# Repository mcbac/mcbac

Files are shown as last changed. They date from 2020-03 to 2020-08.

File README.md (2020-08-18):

# MCBAC

**M**ulti **C**hemistry **B**attery **A**nalyzer and **C**harger - The Software
and Schematic.

MCBAC is a open source (schematic and software), Arduino controled (atmega238),
battery charger and analyzer designed for common battery types. Also can mimic
a power supply, and electronic load.

Comming by late 2020 to mid 2021.

## Purpose

The main purpose of the MCBAC is a affordable, all made in USA, battery
charger, discharger, and analyzer. Able to test batteries of all shapes and
sizes.

## Specification

Please see the [mcbac-v2/README.md](./mcbac-v2/README.md) for details.

## Roadmap

_The roadmap is subject to change without notice._

MCBAC V2.X will be available in low production quantities (maybe 25 units) in
late 2020 to mid 2021. If that is successful, V3 will include cell balancing,
PC/USB controll, and higher output capability, and will be avalibale in higher
quantities (50-100 units).

## License

All files owned by the MCBAC designer(s) and/or MCBAC Technology (the company)
are licensed under the terms of **The Clear BSD License**. See the
[LICENSE file](./LICENSE) for more details.

<br>

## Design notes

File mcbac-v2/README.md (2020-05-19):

# MCBAC Version 2

Comming by late fall 2020 to mid 2021.

These are the design files for mcbac-v2.

## Specification

_Since this is still in pre-production, the specification is subject to change
without notice._

### Input/output
 - Input volts: 7-24v (28v max) (maximum output volts will be 2 volts below the input)
 - Input current: 2.5A max
 - Output volts: 0-15v
 - Output source current: 0-2A
 - Output sink current: 0-2A
 - Output type: linear with buck pre-regulator
 - External temperature sensor (10K NTC)

### Interface
 - 20x4 backlit LCD
 - 2 push buttons
 - 24 step rotary encoder
 - Internal buzzer

### Physical
 - Case: na (dimension not yet available)
 - Internal fan
 - Input: DC power jack (type not yet available)
 - Output: 2X banana jacks
 - Temperature sensor conector: 2 pin JST

<br>

For other infomation about the MCBAC project, see [../README.md](../README.md).

<br>

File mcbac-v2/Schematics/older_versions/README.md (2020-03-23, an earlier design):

This folder contains the older or pre-releases versions of the MCBAC circuit.
See the schematic CHANGELOG for more detail.

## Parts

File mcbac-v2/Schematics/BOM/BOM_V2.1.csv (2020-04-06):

Manufacturer Part Number | Manufacturer | Digi-Key Part Number | Customer Reference | Reference Designator | Packaging | Part Status | Quantity | Unit Price | Extended Price | Description
C0805C104Z5VACTU | KEMET | 399-1177-1-ND |  |  | Cut Tape (CT) | Active | 20 | 0.05700 | $1.14 | CAP CER 0.1UF 50V Y5V 0805
C0805C103K1RAC7210 | KEMET | 399-17617-1-ND |  |  | Cut Tape (CT) | Active | 20 | 0.06800 | $1.36 | CAP CER SMD 0805 .01UF 100V X7R
C0805C220J5GACTU | KEMET | 399-1113-1-ND |  |  | Cut Tape (CT) | Active | 20 | 0.07000 | $1.40 | CAP CER 22PF 50V C0G/NP0 0805
C0805C102J5GACTU | KEMET | 399-1136-1-ND |  |  | Cut Tape (CT) | Active | 20 | 0.09500 | $1.90 | CAP CER 1000PF 50V C0G/NP0 0805
MMBT3906-7-F | Diodes Incorporated | MMBT3906-FDICT-ND |  |  | Cut Tape (CT) | Active | 2 | 0.12000 | $0.24 | TRANS PNP 40V 0.2A SOT23-3
MMBT2907A-7-F | Diodes Incorporated | MMBT2907A-FDICT-ND |  |  | Cut Tape (CT) | Active | 2 | 0.13000 | $0.26 | TRANS PNP 60V 0.6A SOT23-3
MCP6002T-I/SN | Microchip Technology | MCP6002T-I/SNCT-ND |  |  | Cut Tape (CT) | Active | 3 | 0.33000 | $0.99 | IC OPAMP GP 2 CIRCUIT 8SOIC
0751.0062 | Schurter Inc. | 486-1172-ND |  |  | Bulk | Active | 4 | 0.17000 | $0.68 | FUSE CLIP CARTRIDGE 10A PCB
S1M-13-F | Diodes Incorporated | S1M-FDICT-ND |  |  | Cut Tape (CT) | Active | 25 | 0.16360 | $4.09 | DIODE GEN PURP 1KV 1A SMA
ERJ-3GEYJ222V | Panasonic Electronic Components | P2.2KGCT-ND |  |  | Cut Tape (CT) | Active | 10 | 0.04500 | $0.45 | RES SMD 2.2K OHM 5% 1/10W 0603
ERJ-3GEYJ102V | Panasonic Electronic Components | P1.0KGCT-ND |  |  | Cut Tape (CT) | Active | 30 | 0.04400 | $1.32 | RES SMD 1K OHM 5% 1/10W 0603
ERJ-3GEYJ103V | Panasonic Electronic Components | P10KGCT-ND |  |  | Cut Tape (CT) | Active | 30 | 0.04200 | $1.26 | RES SMD 10K OHM 5% 1/10W 0603
ESR03EZPJ101 | Rohm Semiconductor | RHM100DCT-ND |  |  | Cut Tape (CT) | Active | 2 | 0.10000 | $0.20 | RES SMD 100 OHM 5% 1/4W 0603
CRGCQ0603J22K | TE Connectivity Passive Product | A130099CT-ND |  |  | Cut Tape (CT) | Active | 10 | 0.02100 | $0.21 | CRGCQ 0603 22K 5%
RMCF0603FT29K4 | Stackpole Electronics Inc | 738-RMCF0603FT29K4CT-ND |  |  | Cut Tape (CT) | Active | 2 | 0.10000 | $0.20 | RES 29.4K OHM 1% 1/10W 0603
TPS54331DDAR | Texas Instruments | 296-39419-1-ND |  |  | Cut Tape (CT) | Active | 2 | 1.50000 | $3.00 | IC REG BUCK ADJUSTABLE 3A 8SOPWR
LT3083EQ#TRPBF | Linear Technology/Analog Devices | LT3083EQ#TRPBFCT-ND |  |  | Cut Tape (CT) | Active | 1 | 10.44000 | $10.44 | IC REG LINEAR POS ADJ 3A 5DDPAK
B340A-13-F | Diodes Incorporated | B340A-FDICT-ND |  |  | Cut Tape (CT) | Active | 2 | 0.41000 | $0.82 | DIODE SCHOTTKY 40V 3A SMA
860020573008 | Würth Elektronik | 732-8942-1-ND |  |  | Cut Tape (CT) | Active | 2 | 0.14000 | $0.28 | CAP ALUM 100UF 20% 35V RADIAL
860020572001 | Würth Elektronik | 732-8935-1-ND |  |  | Cut Tape (CT) | Active | 2 | 0.10000 | $0.20 | CAP ALUM 4.7UF 20% 35V RADIAL
SDE0604A-5R6M | Bourns Inc. | SDE0604A-5R6MCT-ND |  |  | Cut Tape (CT) | Active | 1 | 0.64000 | $0.64 | FIXED IND 5.6UH 3.2A 75 MOHM SMD
TIP122 | STMicroelectronics | 497-2543-5-ND |  |  | Tube | Active | 2 | 0.64000 | $1.28 | TRANS NPN DARL 100V 5A TO-220
NCP1117DT50G | ON Semiconductor | NCP1117DT50GOS-ND |  |  | Tube | Active | 1 | 0.41000 | $0.41 | IC REG LINEAR 5V 1A DPAK
MCP4725A1T-E/CH | Microchip Technology | MCP4725A1T-E/CHCT-ND |  |  | Cut Tape (CT) | Active | 2 | 0.96000 | $1.92 | IC DAC 12BIT V-OUT SOT23-6
ADS1115IDGSR | Texas Instruments | 296-38849-1-ND |  |  | Cut Tape (CT) | Active | 1 | 5.36000 | $5.36 | IC ADC 16BIT SIGMA-DELTA 10VSSOP
61301011821 | Würth Elektronik | 732-2859-ND |  |  | Tray | Active | 1 | 0.65000 | $0.65 | CONN HDR 10POS 0.1 GOLD PCB
CMI-1295-0585T | CUI Devices | 102-CMI-1295-0585T-ND |  |  | Box | Active | 1 | 1.17000 | $1.17 | BUZZER, 12 MM X 9.5 MM DEEP, M,
MMBT3904-7-F | Diodes Incorporated | MMBT3904-FDICT-ND |  |  | Cut Tape (CT) | Active | 10 | 0.10600 | $1.06 | TRANS NPN 40V 0.2A SMD SOT23-3
LM358DT | STMicroelectronics | 497-1591-1-ND |  |  | Cut Tape (CT) | Active | 2 | 0.46000 | $0.92 | IC OPAMP GP 2 CIRCUIT 8SO
04JQ-BT | JST Sales America Inc. | 455-2967-ND |  |  | Bulk | Active | 1 | 0.43000 | $0.43 | CONN RCPT 4POS 0.098 TIN PCB
B4B-XH-A(LF)(SN) | JST Sales America Inc. | 455-2249-ND |  |  | Bulk | Active | 1 | 0.21000 | $0.21 | CONN HEADER VERT 4POS 2.5MM
08JQ-BT | JST Sales America Inc. | 455-2970-ND |  |  | Bulk | Active | 1 | 0.53000 | $0.53 | CONN RCPT 8POS 0.098 TIN PCB
B8B-XH-AM(LF)(SN) | JST Sales America Inc. | 455-2232-ND |  |  | Bulk | Active | 1 | 0.37000 | $0.37 | CONN HEADER VERT 8POS 2.5MM
3049 | Keystone Electronics | 36-3049-ND |  |  | Bulk | Active | 2 | 0.15000 | $0.30 | WASHER SHOULDER #4 NYLON
HF115AC-0.0055-AC-54 | Bergquist | BER167-ND |  |  | Bulk | Active | 2 | 0.10000 | $0.20 | THERM PAD 19.05MMX12.7MM W/ADH
MF52A2103J3470 | Cantherm | 317-1258-ND |  |  | Bulk | Active | 1 | 0.43000 | $0.43 | THERMISTOR NTC 10KOHM 3470K BEAD
LEDM-2-08 | Essentra Components | RPC4261-ND |  |  | Bulk | Active | 1 | 0.38000 | $0.38 | LED SPACER 3MM T-1 BLACK 8MM
PEC16-4220F-N0024 | Bourns Inc. | PEC16-4220F-N0024-ND |  |  | Tray | Active | 1 | 1.28000 | $1.28 | ROTARY ENCODER MECHANICAL 24PPR
5MF 5-R | Bel Fuse Inc. | 507-1269-ND |  |  | Box | Active | 2 | 0.24000 | $0.48 | FUSE GLASS 5A 125VAC 5X20MM
G5LE-14 DC5 | Omron Electronics Inc-EMC Div | Z1011-ND |  |  | Tray | Active | 2 | 1.44000 | $2.88 | RELAY GEN PURPOSE SPDT 10A 5V
V8818V | Assmann WSW Components | AE10831-ND |  |  | Tray | Active | 2 | 1.50000 | $3.00 | HEATSINK ALUM ANOD
ERT-J1VR103H | Panasonic Electronic Components | P13707CT-ND |  |  | Cut Tape (CT) | Active | 2 | 0.19000 | $0.38 | THERMISTOR NTC 10KOHM 4250K 0603
TFPT0603L1001FM | Vishay Dale | 541-3527-1-ND |  |  | Cut Tape (CT) | Active | 2 | 1.32000 | $2.64 | THERMISTOR PTC 1K OHM 1% 0603
LT3083EQ#PBF | Linear Technology/Analog Devices | LT3083EQ#PBF-ND |  |  | Tube | Active | 1 | 10.28000 | $10.28 | IC REG LINEAR POS ADJ 3A 5DDPAK
MMSZ5231B-7-F | Diodes Incorporated | MMSZ5231B-FDICT-ND |  |  | Cut Tape (CT) | Active | 7 | 0.15000 | $1.05 | DIODE ZENER 5.1V 500MW SOD123
J49SMH-F-G-G-K-16M0 | Jauch Quartz | 1908-J49SMH-F-G-G-K-16M0CT-ND |  |  | Cut Tape (CT) | Active | 1 | 0.24000 | $0.24 | CRYSTAL 16MHZ 18PF SMD
CSRN2512FKR100 | Stackpole Electronics Inc | CSRN2512FKR100CT-ND |  |  | Cut Tape (CT) | Active | 2 | 0.69000 | $1.38 | RES 0.1 OHM 1% 2W 2512

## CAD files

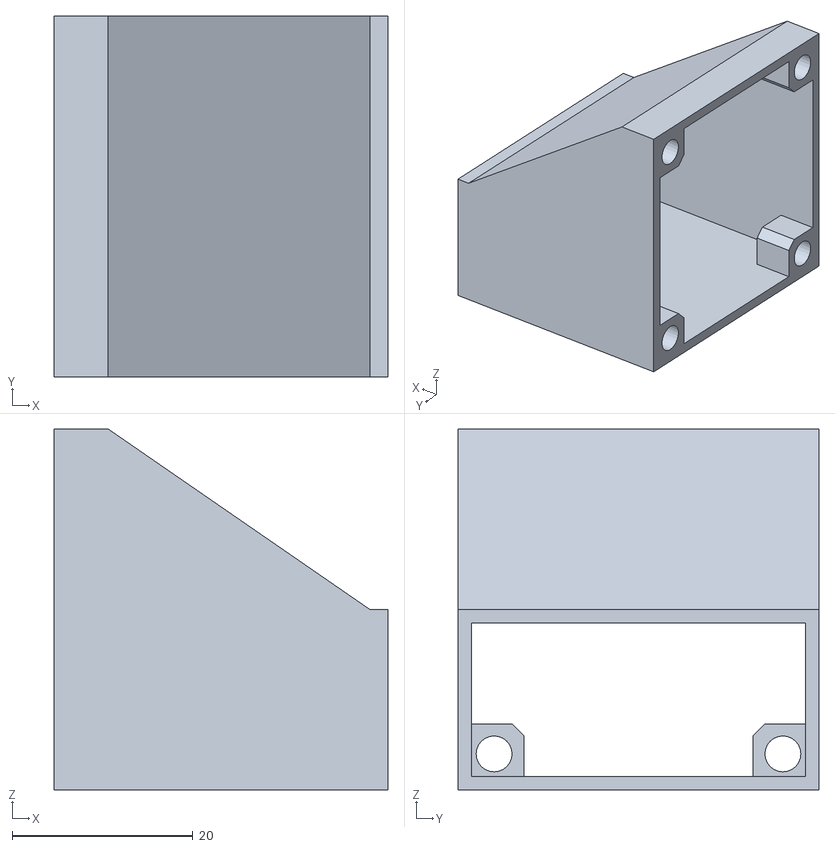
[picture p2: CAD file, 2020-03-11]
mcbac-v2/3D_models/fan_air_flow_director_v3.stl
37.0 x 40.0 x 40.0

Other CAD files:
mcbac-v2/3D_models/fan_air_flow_director_v3.skp

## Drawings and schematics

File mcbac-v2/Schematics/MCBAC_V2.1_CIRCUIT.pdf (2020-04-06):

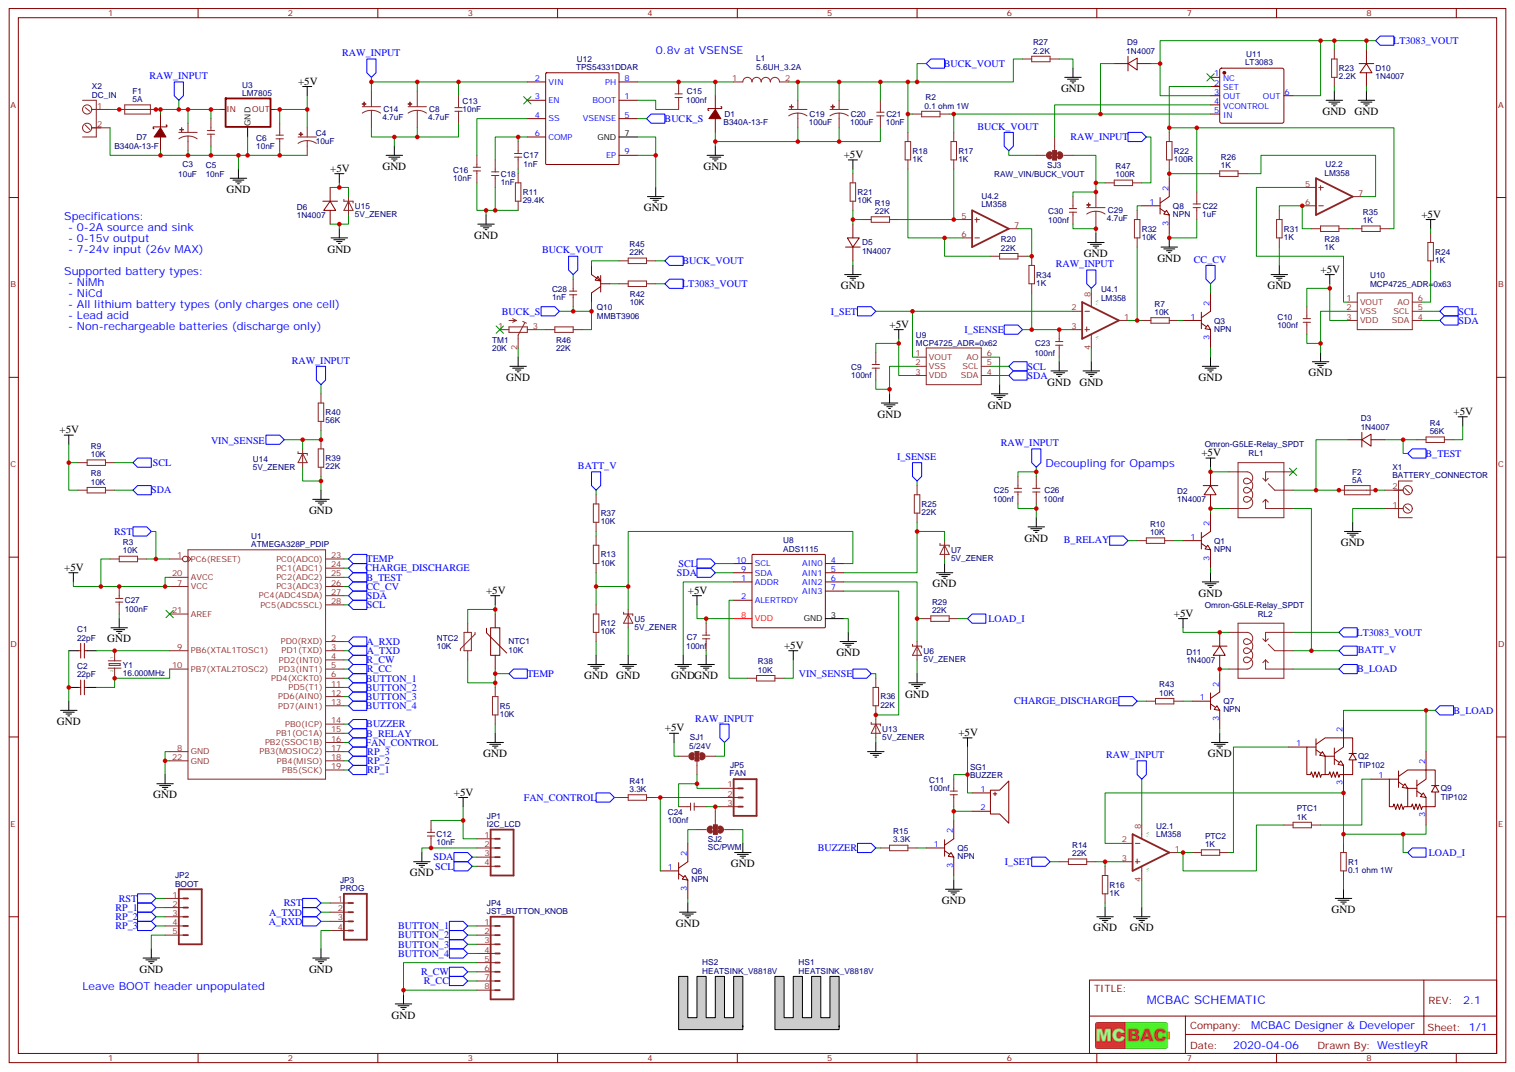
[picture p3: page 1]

C30 Specifications:
- 0-2A source and sink
- 0-15v output
- 7-24v input (26v MAX)
Supported battery types:
- NiMh
- NiCd
- All lithium battery types (only charges one cell)

- Lead acid
- Non-rechargeable batteries (discharge only)

Leave BOOT header unpopulated

Company: MCBAC Designer & Developer

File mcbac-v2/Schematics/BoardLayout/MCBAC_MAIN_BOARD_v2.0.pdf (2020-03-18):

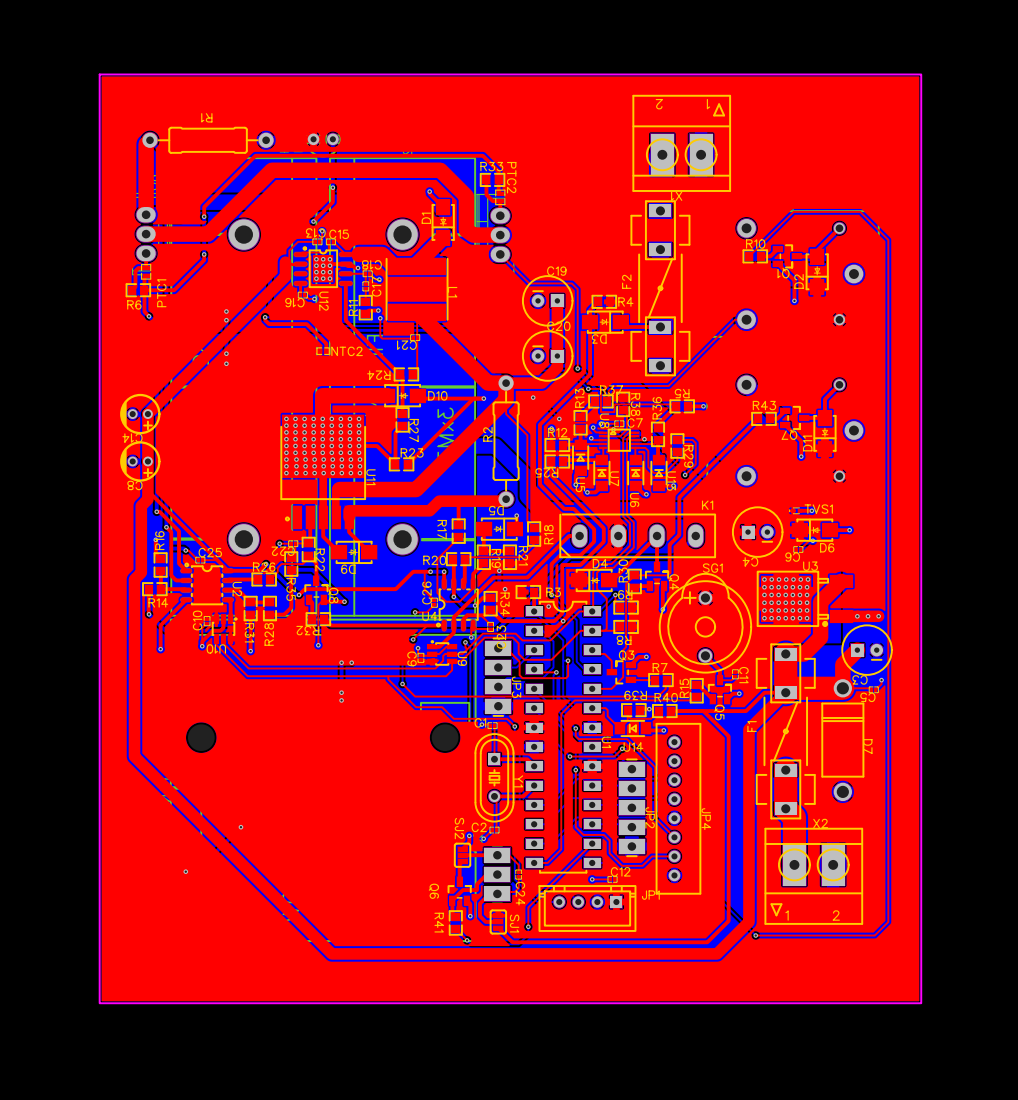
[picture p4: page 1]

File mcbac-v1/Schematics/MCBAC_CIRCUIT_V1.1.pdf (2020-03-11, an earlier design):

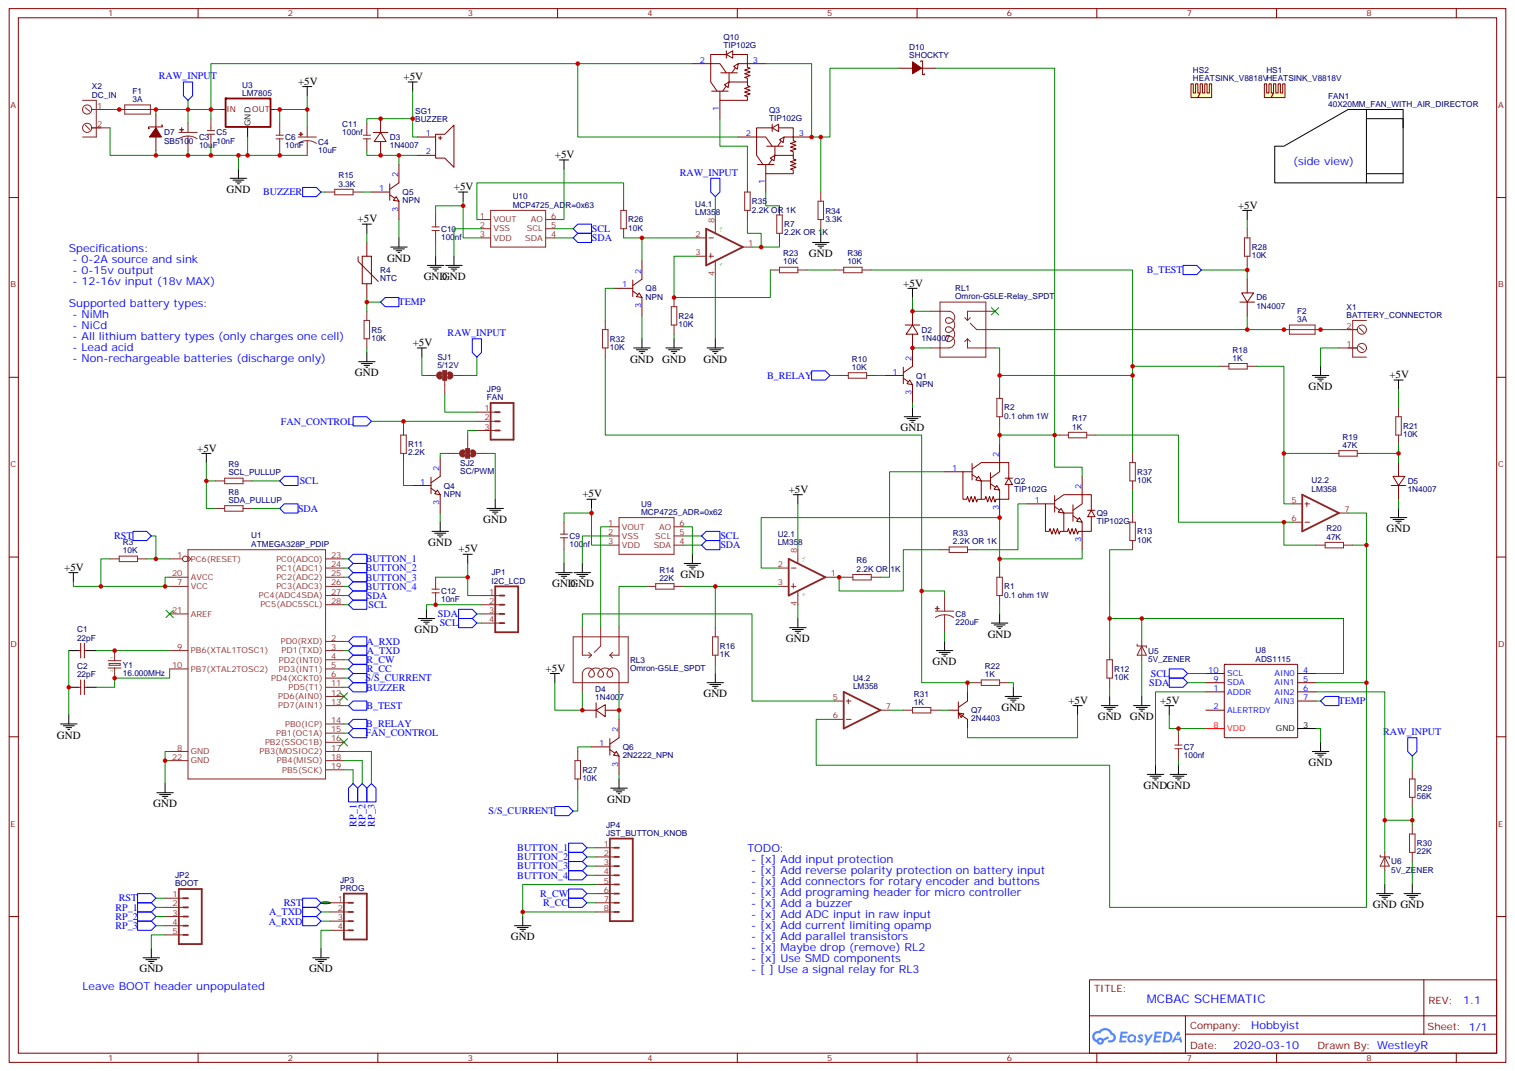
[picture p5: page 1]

Specifications:
- 0-2A source and sink
- 0-15v output
- 12-16v input (18v MAX)
Supported battery types:
- NiMh
- NiCd
- All lithium battery types (only charges one cell)
- Lead acid
- Non-rechargeable batteries (discharge only)

TODO:
- [x] Add input protection
- [x] Add reverse polarity protection on battery input
- [x] Add connectors for rotary encoder and buttons
- [x] Add programing header for micro controller
- [x] Add a buzzer
- [x] Add ADC input in raw input
- [x] Add current limiting opamp
- [x] Add parallel transistors
- [x] Maybe drop (remove) RL2
- [x] Use SMD components
- [ ] Use a signal relay for RL3

Leave BOOT header unpopulated

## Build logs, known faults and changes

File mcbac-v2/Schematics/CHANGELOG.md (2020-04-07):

# MCBAC-V2 Hardware Changelog

**This is the changelog for the MCBAC hardware. The software changelog
is in the Software directory.**

_**NOTE:**_
 1. Versions with "alpha", "a", "beta", "b", or "rc" are pre-releases,
 and subject to change.
 2. This changelog may not include all changes, as this is hand written.

## v2.1.a1 - April 6, 2020

### ADDED
 - Added a `100nF` decoupling cap for `U1` (atmega328)
 - Added a trimmer to adjust the pre-regulator tracking
 - Added 2.2K to buck output
 - Added solder jumper to set the LT3083 `V_CONTROL` to `RAW_INPUT`, or `BUCK_VOUT`

### CHANGES
 - Improvement to the circuit diagram
 - Changed the `0201` caps to `0805`
 - Fixed buck converter feedback using PNP transistor
 - Changed the `Y1` (crystal) to SMD
 - Changed `R1`, and `R2` (current shunts) to `2512` SMD
 - Changed the `TEMP` read from `U8` -> `U1` (read `TEMP` from `U1`s builtin ADC)
 - Changed `PTC1`, and `PTC2` from `0201` -> `0406`
 - Changed `NTC2` from `0201` -> `0406`

### REMOVED
 - Removed unknown value resistors in parallel with `PTC1`, and `PTC2`
 - Removed the 40X20mm blower fan (maybe will use a squirrel fan)
 - Removed the unnecessary reed relay

## v2.0 - March 17, 2020

Basic prototype circuit.

<br>

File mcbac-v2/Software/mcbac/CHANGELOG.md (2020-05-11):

# MCBAC-V2 Software Changelog

**This is the changelog for the MCBAC software. The hardware changelog
is in the Schematic directory.**

_**NOTE:**_
 1. Versions with "alpha", "a", "beta", "b", or "rc" are pre-releases,
 and subject to change.
 2. This changelog may not include all changes, as this is hand written.

## v1.0.0.b4 - May 11, 2020

Init release.

<br>

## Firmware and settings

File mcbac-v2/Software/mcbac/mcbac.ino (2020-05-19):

// Created by: WestleyR
// Email: westleyr@nym.hush.com
// Url: https://github.com/WestleyR/mcbac
// Last modified date: 2020-05-19
//
// This file is licensed under the terms of
//
// The Clear BSD License
//
// Copyright (c) 2020 WestleyR
// All rights reserved.
//
// This software is licensed under a Clear BSD License.
//

#include <Wire.h>

#include "FaBoLCD_PCF8574.h"
#include "Adafruit_MCP4725.h"
#include "Adafruit_ADS1015.h"

#define MCBAC_VERSION "v1.0.0-beta-4"
#define MCBAC_DATE "May 11, 2020"

#define buttonEnter 4
#define buttonBack 5
#define buttonUp 6
#define buttonDown 7

#define buzzer 8
#define battery_relay 9
#define charge_discharge_relay A1
#define CC_CV A3

#define R_CW 2
#define R_CC 3

// 20x4 LCD with I2C adaptor
FaBoLCD_PCF8574 lcd;

Adafruit_MCP4725 dacVout;
Adafruit_MCP4725 dacIout;
Adafruit_ADS1115 adc;

void setup() {
  pinMode(buttonEnter, INPUT_PULLUP);
  pinMode(buttonBack, INPUT_PULLUP);
  pinMode(buttonUp, INPUT_PULLUP);
  pinMode(buttonDown, INPUT_PULLUP);

  pinMode(buzzer, OUTPUT);
  pinMode(battery_relay, OUTPUT);
  pinMode(charge_discharge_relay, OUTPUT);
  pinMode(CC_CV, INPUT);

  digitalWrite(buzzer, LOW);
  digitalWrite(battery_relay, LOW);
  digitalWrite(charge_discharge_relay, LOW);

  pinMode(8, OUTPUT);
  digitalWrite(8, HIGH);

  pinMode(R_CW, INPUT_PULLUP);
  pinMode(R_CC, INPUT_PULLUP);

  dacVout.begin(0x63);

  // Make sure the output is zero
  setVOut(0);

  dacIout.begin(0x62);

  // Make sure the output is zero
  setIOut(0);

  adc.begin();

  // Initialize the LCD
  lcd.begin(20, 4);

  // Rotary encoder
  attachInterrupt(0, cursorCW, RISING);
  attachInterrupt(1, cursorCC, RISING);

  // For debugging/logging
  Serial.begin(9600);

  // Print version, and info
  //lcd.backlight();
  lcd.setCursor(0, 0);
  lcd.print("MCBAC ");
  lcd.print(MCBAC_VERSION);
  lcd.setCursor(0, 1);
  lcd.print(MCBAC_DATE);
  delay(250);
  lcd.clear();
  lcd.setCursor(1, 0);
  lcd.print("Copyright WestleyR");
  lcd.setCursor(3, 1);
  lcd.print("This divice is");
  lcd.setCursor(1, 2);
  lcd.print("licensed under The");
  lcd.setCursor(1, 3);
  lcd.print("Clear BSD License.");
  delay(250);
  lcd.clear();
  lcd.setCursor(0, 0);
  lcd.print("https://github.com/");
  lcd.setCursor(3, 1);
  lcd.print("WestleyR/mcbac");
  delay(250);
  lcd.clear();
  lcd.setCursor(0, 0);
}

// When 1; update the LCD
int updateDisplay = 1;

// For the rotory encoder
volatile int lastCW;
volatile int lastCC;
volatile int cursorCount;
volatile int cursorRow;

// To remember the battery program
// 1 = lipo
// 2 = ninh
// ...
int batteryProg;

int enterB = 0;
int backB = 0;
int upB = 0;
int downB = 0;

void resetAllButtons() {
  enterB = 0;
  backB = 0;
  upB = 0;
  downB = 0;
}

void cursorCW() {
  cli();
  // Read pins D, and only keep pins 2 and 3
  byte reading = PIND & B00001100;
  if (reading == B00001100 && lastCW == 1) {
    // TODO: changed to -- untill fixed wires
    cursorCount--;
    updateDisplay = 1;
    lastCW = 0;
    lastCC = 0;
    if (cursorCount <= 0) cursorCount = 0;
  } else if (reading == B00001000) {
    lastCC = 1;
  }
  sei();
}

void cursorCC() {
  cli();
  // Read pins D, and only keep pins 2 and 3
  byte reading = PIND & B00001100;
  if (reading == B00001100 && lastCC == 1) {
    // TODO: changed to ++ untill fixed wires
    cursorCount++;
    updateDisplay = 1;
    lastCC = 0;
    lastCW = 0;
  } else if (reading == B00000100) {
    lastCW = 1;
  }
  sei();
}

int checkButtons() {
  if (digitalRead(buttonEnter) == LOW) {
    enterB = 1;
    delay(150);
    return 1;
  } else if (digitalRead(buttonBack) == LOW) {
    backB = 1;
    delay(150);
    return 2;
  } else if (digitalRead(buttonUp) == LOW) {
    upB = 1;
    delay(150);
    return 3;
  } else if (digitalRead(buttonDown) == LOW) {
    downB = 1;
    delay(150);
    return 4;
  }
  resetAllButtons();
  return 0;
}

int outputVOffset = 0;

// volts can be 0.00-15.00
void setVOut(float volts) {
  // 4096 is the max value

  int v = volts * 273;
  v += outputVOffset;
  if (v < 0) v = 0;
  if (v > 4096) v = 4096;
  dacVout.setVoltage(v, false);
}

// TODO: Fix this to real values
const static int CURRENT_OFFSET = 0;
const static float CURRENT_CAL = 0.65;

int outputIOffset = 0;

// Current can be from 0-2000;
void setIOut(int ma) {
  // 4096 is the max value

  // TODO: FIXME:
  //int i = (ma + CURRENT_OFFSET) / CURRENT_CAL;
  int i = 520;
  i += ma * 4.25;
  i += outputIOffset;
  dacIout.setVoltage(i, false);
}

void setLCDPointer(int line) {
  if (line == 0) {
    lcd.setCursor(0, 0);
    lcd.print("> ");
    lcd.setCursor(0, 1);
    lcd.print("  ");
    lcd.setCursor(0, 2);
    lcd.print("  ");
    lcd.setCursor(0, 3);
    lcd.print("  ");
  } else if (line == 1) {
    lcd.setCursor(0, 0);
    lcd.print("  ");
    lcd.setCursor(0, 1);
    lcd.print("> ");
    lcd.setCursor(0, 2);
    lcd.print("  ");
    lcd.setCursor(0, 3);
    lcd.print("  ");
  } else if (line == 2) {
    lcd.setCursor(0, 0);
    lcd.print("  ");
    lcd.setCursor(0, 1);
    lcd.print("  ");
    lcd.setCursor(0, 2);
    lcd.print("> ");
    lcd.setCursor(0, 3);
    lcd.print("  ");
  } else if (line == 3) {
    lcd.setCursor(0, 0);
    lcd.print("  ");
    lcd.setCursor(0, 1);
    lcd.print("  ");
    lcd.setCursor(0, 2);
    lcd.print("  ");
    lcd.setCursor(0, 3);
    lcd.print("> ");
  }
}

// Battery values
int batteryRun;
int batteryCurrent = 100;
int safetyTimer = 120;
int batteryCutoff = 100;
int batteryCutoffMAH = 5000;
int batteryType;
float batteryNom;
float batteryEndVolts;
float batteryVoltLimit = 4.00;
float batteryDeltaV = 5.00;
String batteryName;
bool batteryPulseCharge = true;

void setDecadeValue(float *value, float inc, bool dec, int updateValue, int cur, int line) {
  cursorCount = 128;
  int lastCount = cursorCount;
  int decadeCount = 100;
  int blinkCursor;
  updateDisplay = 1;
  lcd.setCursor(cur, line);
  lcd.cursor();
  // Wait for the user to set the end voltage
  while (digitalRead(buttonBack) == HIGH) {
    if (updateDisplay == 1) {
      if (lastCount > cursorCount) {
        *value -= (inc * decadeCount);
        lastCount = cursorCount;
        if (updateValue == 1) {
          setVOut(*value);
        } else if (updateValue == 2) {
          //setIOut((int)*value);
          batteryCurrent = (int) * value;
        }
        updateDisplay = 0;
      } else if (lastCount < cursorCount) {
        *value += (inc * decadeCount);
        lastCount = cursorCount;
        if (updateValue == 1) {
          setVOut(*value);
        } else if (updateValue == 2) {
          //setIOut((int)*value);
          batteryCurrent = (int) * value;
        }
        updateDisplay = 0;
      }

      lcd.setCursor(cur, line);
      if (dec) {
        lcd.print(*value);
      } else {
        lcd.print((int)*value);
        if (*value == 0) lcd.print("  ");
      }
      lcd.print(" ");
      if (decadeCount == 100) {
        blinkCursor = cur;
      } else if (decadeCount == 10) {
        blinkCursor = cur + 1;
        if (dec) blinkCursor++;
      } else if (decadeCount == 1) {
        blinkCursor = cur + 2;
        if (dec) blinkCursor++;
      }
      if (dec) {
        if (*value >= 10) blinkCursor++;
      } else {
        if (*value >= 1000) blinkCursor++;
      }
      lcd.setCursor(blinkCursor, line);

      updateDisplay = 0;
    }

    // Update the volts if in power supply mode
    if (updateValue == 1 || updateValue == 2) readVolts(blinkCursor, line);

    checkButtons();
    if (enterB == 1) {
      enterB = 0;
      decadeCount /= 10;
      updateDisplay = 1;
      if (decadeCount < 1) break;
    }
  }
  lcd.noCursor();
  delay(250);
}

float batteryMWH;
unsigned long lastUpdated = millis();

#define BETWEEN(value, min, max) (value < max && value > min)
#define CV true
#define CC false
#define MAX_OFFSET 50

bool vcal = false;

// FixOutputVolts will slightly adjust the real volts to match the set volts
void fixOutputVolts(bool supplyMode, float real, float set) {
  // Only fix the output if in CV mode
  if (supplyMode == CV) {
    if (real < set) {
      outputVOffset += 1;
    } else if (real > set) {
      outputVOffset -= 1;
    }
    if (outputVOffset > MAX_OFFSET) outputVOffset = MAX_OFFSET;
    if (outputVOffset < -MAX_OFFSET) outputVOffset = -MAX_OFFSET;
    setVOut(batteryEndVolts);
  }
}

void fixOutputCurrent(bool supplyMode, float real, float set) {
  // Only fix the output if in CC mode
  if (supplyMode == CC) {
    if (real < set) {
      outputIOffset += 1;
    } else if (real > set) {
      outputIOffset -= 1;
    }
    if (outputIOffset > MAX_OFFSET) outputIOffset = MAX_OFFSET;
    if (outputIOffset < -MAX_OFFSET) outputIOffset = -MAX_OFFSET;
    setIOut(batteryCurrent);
  }
}

float i;
float v;
bool supplyMode;

// readVolts will read the volts, update the display, and do small adjustments to the output
// if needed. Used in Power Supply mode.
void readVolts(int row, int line) {
  // Read the volts
  v = adc.readADC_SingleEnded(0);
  // Calabrate the voltage
  v = v / 1750;

  // Now read the current
  i = adc.readADC_SingleEnded(1);
  // Remove the diff opamp offset, then the calabrate value
  i = (i - 3561) / 25.4;
  if (i < 0) {
    i = 0;
  }

  // Only update every 0.5s
  if (millis() - lastUpdated > 500) {
    // Print the volts
    lcd.setCursor(4, 1);
    lcd.print(v);
    lcd.print(" ");

    // Print the current
    lcd.setCursor(4, 2);
    lcd.print((int)i);
    lcd.print("   ");

    // Print the Watts
    lcd.setCursor(4, 3);
    float w = (i / 1000) * v;
    if (w < 0) {
      lcd.print("0.00");
      w = 0;
    } else {
      lcd.print(w);
    }
    lcd.print(" ");

    // Print the mWH
    unsigned long t = millis() - lastUpdated;
    float mwh = (t * w) / 36;
    batteryMWH += mwh;

    lcd.setCursor(14, 3);
    lcd.print((int)(batteryMWH / 100));
  
    lastUpdated = millis();
  }

  // Fix the output error only if current is 0
  if (i == 0) fixOutputVolts(CV, v, batteryEndVolts);

  lcd.setCursor(18, 0);
  if (((batteryEndVolts - v) >= 0.02) || ((batteryEndVolts - v) <= -0.02)) {
    lcd.print("CC");
    fixOutputCurrent(CC, i, batteryCurrent);
  } else {
    lcd.print("CV");
  }

  if (row != -1 && line != -1) lcd.setCursor(row, line);
}

void powerSupply() {
  int batteryAdjust;
  int updateOutput = 1;
  cursorCount = 0;

  digitalWrite(battery_relay, HIGH);
  digitalWrite(charge_discharge_relay, LOW);

  while (digitalRead(buttonBack) == HIGH) {
    if (updateOutput == 1) {
      setVOut(batteryEndVolts);
      setIOut(batteryCurrent);
    }
    if (updateDisplay == 1) {
      lcd.clear();
      lcd.setCursor(4, 0);
      lcd.print("Power Supply");
      lcd.setCursor(0, 1);
      lcd.print("  V ");
      lcd.setCursor(10, 1);
      lcd.print("SET ");
      lcd.print(batteryEndVolts);
      lcd.setCursor(0, 2);
      lcd.print("  I ");
      lcd.setCursor(10, 2);
      lcd.print("SET ");
      lcd.print(batteryCurrent);
      lcd.setCursor(0, 3);
      lcd.print("  W ");
      lcd.setCursor(10, 3);
      lcd.print("mWH ");
      updateDisplay = 0;
    }

    if (cursorCount == 0) {
      setLCDPointer(1);
      updateDisplay = 0;
      batteryAdjust = 1;
    } else if (cursorCount == 1) {
      setLCDPointer(2);
      updateDisplay = 0;
      batteryAdjust = 2;
    } else {
      cursorCount = 1;
    }
    readVolts(-1, -1);
    checkButtons();
    if (enterB == 1) {
      int lastCursorState = cursorCount;
      enterB = 0;
      if (batteryAdjust == 1) { // Volts
        setDecadeValue(&batteryEndVolts, 0.01, true, 1, 14, 1);
        batteryAdjust = 0;
        updateOutput = 1;
      } else if (batteryAdjust == 2) { // Current
        float c = float(batteryCurrent);
        setDecadeValue(&c, 1, false, 2, 14, 2);
        batteryCurrent = c;
        batteryAdjust = 0;
        updateOutput = 1;
      }
      cursorCount = lastCursorState;
    }
  }

  digitalWrite(battery_relay, LOW);

  lcd.clear();
  lcd.setCursor(0, 0);

  lcd.print("End Power Supply");
  lcd.setCursor(0, 1);
  lcd.print("Total mWH: ");
  lcd.setCursor(0, 2);
  lcd.print(batteryMWH);

  delay(200);
  while (digitalRead(buttonBack) == HIGH) {
    checkButtons();
    if (enterB == 1) {
      enterB = 0;
      break;
    }
  }

  updateDisplay = 1;
}

void chargeCVBattery() {
  while (digitalRead(buttonBack) == HIGH) {
    if (updateDisplay == 1) {
      lcd.clear();
      lcd.setCursor(0, 0);
      lcd.print("C: ");
      lcd.print(batteryName);
      lcd.setCursor(0, 1);
      lcd.print("V ");
      lcd.print(00.00);
      lcd.print("   CV ");
      lcd.print(batteryEndVolts);
      lcd.setCursor(0, 2);
      lcd.print("I ");
      lcd.print(0000);
      lcd.print("  IL ");
      lcd.print(batteryCurrent);
      lcd.setCursor(0, 3);
      lcd.print("T ");
      lcd.print(000);
      lcd.print("  CT ");
      lcd.print(safetyTimer);
      updateDisplay = 0;
    }
    checkButtons();
  }
  lcd.clear();
  lcd.setCursor(0, 0);

  lcd.print("Done charging");
  lcd.setCursor(0, 1);
  lcd.print("mah na");

  delay(200);
  while (digitalRead(buttonBack) == HIGH) {
    checkButtons();
    if (enterB == 1) {
      enterB = 0;
      break;
    }
  }

  updateDisplay = 1;
}

void dischargeCC(String batteryName, int batteryCurrent, float batteryEndVolts, int batteryCutoff, int safetyTimer) {
  while (digitalRead(buttonBack) == HIGH) {
    if (updateDisplay == 1) {
      lcd.clear();
      lcd.setCursor(0, 0);
      lcd.print("D: ");
      lcd.print(batteryName);
      lcd.setCursor(0, 1);
      lcd.print("V ");
      lcd.print(00.00);
      lcd.print("  EndV ");
      lcd.print(batteryEndVolts);
      lcd.setCursor(0, 2);
      lcd.print("I: ");
      lcd.print(0000);
      lcd.print("  Iset ");
      lcd.print(batteryCurrent);
      lcd.setCursor(0, 3);
      lcd.print("T ");
      lcd.print(000);
      lcd.print("  Tcut ");
      lcd.print(safetyTimer);
      updateDisplay = 0;
    }
    checkButtons();
  }
  //lcd.clear();
  lcd.setCursor(0, 0);

  lcd.print("Done: ");
  lcd.print(batteryName);

  delay(200);
  while (digitalRead(buttonBack) == HIGH) {
    checkButtons();
    if (enterB == 1) {
      enterB = 0;
      break;
    }
  }

  updateDisplay = 1;
}

void chargeLiBattery() {
  if (batteryType == 1) { // Lithium type
    if (batteryRun == 1) {
      // Charge
      if (setCVFunc() != 0) {
        cursorCount = 0;
        updateDisplay = 1;
        return;
      }
      chargeCVBattery();

    } else if (batteryRun == 2) {
      // Discharge
      if (setCCDFunc() != 0) {
        return;
        cursorCount = 0;
        updateDisplay = 1;
      }
      dischargeCC(batteryName, batteryCurrent, batteryEndVolts, batteryCutoff, safetyTimer);

    } else if (batteryRun == 3) {
      // Cycle test
    } else if (batteryRun == 4) {
      // SoC test
    }
  } else if (batteryType == 2) { // Nickel type
    if (batteryRun == 1) {
      // Charge
      if (setCCFunc() != 0) {
        cursorCount = 0;
        updateDisplay = 1;
        return;
      }
      chargeCVBattery();

    } else if (batteryRun == 2) {
      // Discharge
      if (setCCDFunc() != 0) {
        return;
        cursorCount = 0;
        updateDisplay = 1;
      }
      dischargeCC(batteryName, batteryCurrent, batteryEndVolts, batteryCutoff, safetyTimer);

    } else if (batteryRun == 3) {
      // Cycle test
    } else if (batteryRun == 4) {
      // SoC test
    }
  } else if (batteryType == 3) {
    // Lead acid
  } else if (batteryType == 4) { // Power supply
    powerSupply();

  } else if (batteryType == 5) {
    // DC load
  }


  updateDisplay = 1;
  cursorCount = 0;
}

int batteryMAH = 100;

int setCVFunc() {
  int batteryAdjust;
  int updateScroll = 1;
  int page = 1;

  while (digitalRead(buttonBack) == HIGH) {
    if (cursorCount == 0) {
      setLCDPointer(0);
      updateDisplay = 0;
      batteryAdjust = 1;
    } else if (cursorCount == 1) {
      setLCDPointer(1);
      updateDisplay = 0;
      batteryAdjust = 2;
    } else if (cursorCount == 2) {
      setLCDPointer(2);
      updateDisplay = 0;
      batteryAdjust = 3;
    } else if (cursorCount == 3) {
      setLCDPointer(3);
      updateDisplay = 0;
      batteryAdjust = 4;
      if (page == 2) {
        page = 1;
        updateScroll = 1;
      }
    } else if (cursorCount == 4) {
      if (page == 1) {
        page = 2;
        updateScroll = 2;
      }
      setLCDPointer(0);
      updateDisplay = 0;
      batteryAdjust = 5;
    } else if (cursorCount == 5) {
      setLCDPointer(1);
      updateDisplay = 0;
      batteryAdjust = 6;
    } else if (cursorCount == 6) {
      lcd.setCursor(0, 0);
      lcd.print("  ");
      lcd.setCursor(0, 1);
      lcd.print("G ");
      lcd.setCursor(0, 2);
      lcd.print("O ");
      lcd.setCursor(0, 3);
      lcd.print("  ");
      updateDisplay = 0;
      batteryAdjust = 7;
    } else {
      cursorCount = 6;
    }

    if (updateScroll == 1) {
      lcd.clear();
      lcd.setCursor(2, 0);
      lcd.print("Battery mAH ");
      lcd.print(batteryMAH);

      lcd.setCursor(2, 1);
      lcd.print("Charge ");
      lcd.print(batteryCurrent);
      lcd.print(" C");
      lcd.print((float)((float)batteryCurrent / (float)batteryMAH));

      lcd.setCursor(2, 2);
      lcd.print("End volts ");
      lcd.print(batteryEndVolts);

      lcd.setCursor(2, 3);
      lcd.print("Cutoff MA ");
      lcd.print(batteryCutoff);
      updateScroll = 0;
    } else if (updateScroll == 2) {
      // Shift the display down
      lcd.clear();
      lcd.setCursor(2, 0);
      lcd.print("Safety timer ");
      lcd.print(safetyTimer);

      lcd.setCursor(2, 1);
      lcd.print("Cutoff MAH  ");
      lcd.print(batteryCutoffMAH);
      updateScroll = 0;
    }

    checkButtons();
    if (backB == 1) break; // return 1 as user pushed the back button
    if (enterB == 1) {
      int lastCursorState = cursorCount;
      enterB = 0;
      if (batteryAdjust == 1) { // Battery mAH
        float c = batteryMAH;
        setDecadeValue(&c, 1, false, 0, 14, 0);
        batteryMAH = c;

        // Charge the battery at 1C (by default), if under 2Amps
        batteryCurrent = batteryMAH * 1; // The default charge rate
        if (batteryCurrent > 2000) batteryCurrent = 2000;
        if (page == 1) updateScroll = 1;

        // 110% of the battery capacity for the mAH cutoff
        batteryCutoffMAH = batteryMAH * 1.1;

        batteryAdjust = 0;
      } else if (batteryAdjust == 2) { // Charge mA
        float c = batteryCurrent;
        setDecadeValue(&c, 1, false, 0, 9, 1);
        batteryCurrent = c;
        if (page == 1) updateScroll = 1;
        batteryAdjust = 0;
      } else if (batteryAdjust == 3) { // End V
        setDecadeValue(&batteryEndVolts, 0.01, true, 0, 12, 2);
        batteryAdjust = 0;
      } else if (batteryAdjust == 4) { // Cutoff MAH
        float c = batteryCutoff;
        setDecadeValue(&c, 1, false, 0, 12, 3);
        batteryCutoff = c;
        batteryAdjust = 0;
      } else if (batteryAdjust == 5) { // Safety timer
        float t = safetyTimer;
        setDecadeValue(&t, 1, false, 0, 15, 0);
        safetyTimer = t;
        batteryAdjust = 0;
      } else if (batteryAdjust == 6) { // Cutoff mAH
        float c = batteryCutoffMAH;
        setDecadeValue(&c, 1, false, 0, 14, 1);
        batteryCutoffMAH = c;
        batteryAdjust = 0;
      } else if (batteryAdjust == 7) { // GO
        enterB = 0;
        updateDisplay = 1;
        cursorCount = 0;
        // User said to start the function
        return 0;
      }
      cursorCount = lastCursorState;
    }
  }
  updateDisplay = 1;

  return 1;
}
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
void loop() {
  checkButtons();
  mainMenu();
}

// vim: tabstop=2 shiftwidth=2 expandtab autoindent softtabstop=0

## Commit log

2020-03-03 Updated code; added rotary encoder
2020-03-04 Added charge config
2020-03-04 Added more battery types
2020-03-04 Cleaned code, added CV charge function
2020-03-04 Fixing nickel battery charging adjust
2020-03-04 Added/fixed charge code
2020-03-05 Cleaned battery vars, lcd chars
2020-03-05 Cleanup before real world voltage test
2020-03-11 Updated power supply code
2020-03-11 Fixing lipo charge func
2020-03-11 Cleaned/updated lipo/li-ion charge setup
2020-03-11 Added 3D models, and Schematics
    [fan_air_flow_director_v2.skp, fan_air_flow_director_v2.stl, fan_air_flow_director_v3.skp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]
2020-03-11 Added working ADC and update the volts value
2020-03-11 Print live current in power supply mode
2020-03-12 Fixing current cal
2020-03-13 Working power supply mode, with Watts and mWh
2020-03-14 Added error fixing to power supply mode
2020-03-14 Added the start of V2 (new schematic)
    [fan_air_flow_director_v2.skp, fan_air_flow_director_v2.stl, fan_air_flow_director_v3.skp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]
2020-03-14 Updated v2 circuit
2020-03-14 Updated v2 schematic (added heatsink)
2020-03-15 Added main board V2, with updated schematic
    [Gerber_BoardOutline.GKO, Gerber_BottomLayer.GBL, Gerber_BottomSolderMaskLayer.GBS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]
2020-03-16 Updated mcbac v2 circuit feedback
    [Gerber_BoardOutline.GKO, Gerber_BottomLayer.GBL, Gerber_BottomSolderMaskLayer.GBS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]
2020-03-17 Updated main circuit
2020-03-18 Added BoardLayout + updated schematics
2020-04-02 Fixed schematic for v2.1
    [fan_air_flow_director_v2.skp, fan_air_flow_director_v2.stl, mcbac_box_v1.0.skp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]
2020-04-03 Some schematics changes to pre-regulator
2020-04-06 Added logos, BOM, and updated schematic
    [BOM_V2.1.csv]
2020-04-07 Fixing code to work with new circuit
    [mcbac.ino]
2020-04-08 Add support for output relay
